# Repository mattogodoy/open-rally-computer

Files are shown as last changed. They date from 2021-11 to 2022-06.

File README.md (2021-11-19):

# Open Rally Computer

An open source tripmaster for navigation rallies

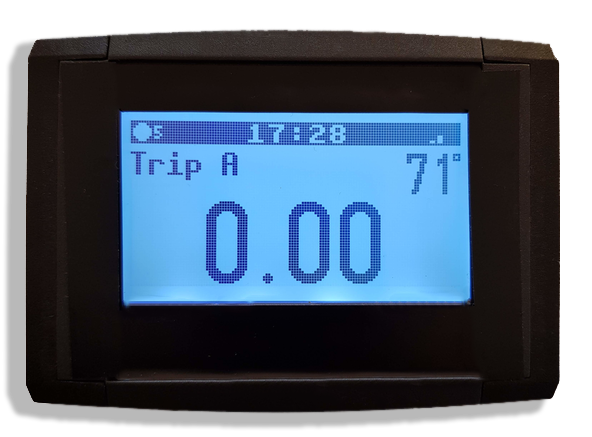
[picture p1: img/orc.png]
Open Rally Computer


## Description

The Open Rally Computer (previously known as [Baja Pro](https://baja.matto.io/)) is a complete tripmaster for navigation rallies.

Some of its features are:

- Based on GPS technology
- Adjustable partial distance odometer
- Total distance odometer
- Speedometer
- Average speed
- Max speed
- Trip time
- Compass (CAP heading)
- Multiple languages and unit systems
- Firmware updates over-the-air

The main goal of this project is to achieve a widely used open-source device that can be improved over time by ourselves, the pilots behind the roadbook.

You can read a detailed writeup of the project here:

- [English version](https://matto.io/open-sourcing-the-baja-pro/)
- [Spanish version](https://matto.io/liberando-el-codigo-del-baja-pro/)

## Schematics and PCB

You can find all the necessary information for fabricating your own copy of the Open Rally Computer PCB in the [pcb](docs/pcb) and [schematics](docs/schematics) folders of this repository.

> **HELP NEEDED**: My knowledge in electronics is self-taught, so I'm sure there are quite a few improvements to be done in this department. If you know electronics and spot something that can be improved, please let me know by opening an issue.

- Previous models of this device have been fabricated at [JLCPCB](https://jlcpcb.com/) with great results and very good prices.
- The system I used to create the PCB was [EasyEDA](https://easyeda.com/). You can find files for the schematics and the PCB in their relative folders. There are also versions for Altium Designer.

> **HELP NEEDED**: I'd like to port these schematics and PCB to KiCad, so we continue with the open source spirit :)
>
> If you know your way around KiCad, I'd really appreciate some help porting this board.

The bill of materials is located in a CSV file in the [bom](docs/pcb/bom) folder. If you find a missing component, please report it by opening an issue.

## User manual

You can find a PDF version of the User Manual in the [manual](docs/manual) folder.

> **HELP NEEDED**: The user manual is currently only in Spanish and it still has a lot of Baja Pro branding that has to be changed to "Open Rally Computer". I'd really appreciate some help transcribing it to Markdown and translating it into other languages, being english the top priority right now.

## Getting Started

These instructions will allow you to compile the project in you local computer. In order to run it you will need an actual device.

### Prerequisites

This project has been developed using VSCode with the PlatformIO plugin, which is is the recommended setup.

- Install [VSCode](https://code.visualstudio.com/)
- Install the [PlatformIO plugin](https://platformio.org/install/ide?install=vscode)
- Clone this repository

```bash
git clone https://github.com/mattogodoy/open-rally-computer.git
```

### Building

To build this project you can open the directory of the repository you just downloaded in VSCode.

Once open, go to the sidebar at the left, PlatformIO -> esp32dev -> General -> Build

The required libraries are already bundled in the `lib` directory of this repo. PlatformIO will automatically try to use them.
If for some reason you are getting compilation errors because of missing libraries, you can always install them manually going to PlatformIO -> PIO Home -> Libraries.

You can find the list of necessary libraries in the file [platformio.ini](platformio.ini).

## Flashing into device

Once the project compiles correctly in your computer, you are ready to flash it into the rally computer.

1. Connect your ESP32 (DevKit or programmer) to your computer via USB.
2. Go to PlatformIO -> esp32dev -> General -> Upload
3. PlatformIO should automatically detect the serial port where your ESP32 is connected, buld the project and flash it for you.

## Contributing

Please read [CONTRIBUTING.md](CONTRIBUTING.md) for details on the process for submitting pull requests.

Also read [CODE_OF_CONDUCT.md](CODE_OF_CONDUCT.md) for details on the code of conduct for this project.

## Versioning

We use [SemVer](http://semver.org/) for versioning.

For a list of available versions, see the [tags on this repository](https://github.com/mattogodoy/open-rally-computer/tags).

## Authors

- **Matías Godoy** - [matto.io](https://matto.io/)

See also the list of [contributors](https://github.com/mattogodoy/open-rally-computer/graphs/contributors) who participated in this project.

## TO-DO

There are a few things I'd like to do in order to improve this project and its repository:

- [x] Build, upload and tag Version 1.0.0 binary as a release
- [x] Translate user manual to english
- [ ] Port the PCB files to KiCad
- [ ] Create proper documentation in GitHub Wiki
- [ ] Create Continuous Integration using GitHub Actions

## License

This project is licensed under the GPL v3 License - see the [LICENSE](LICENSE) file for details.

This is what this means:

1. Anyone can copy, modify and distribute this software.
2. If you do, you have to include the license and copyright notice with each and every distribution.
3. You can use this software privately.
4. You can use this software for commercial purposes.
5. If you build your business based on this code, you have to open-source your whole code base.
6. Any modifications of this code base MUST be distributed with the same license (GPL v3).
7. Any changes made to this code MUST be indicated on distribution.
8. This software is provided without warranty.
9. The software author or license can not be held liable for any damages inflicted by the software.

## Changelog

- **1.0.0**: Initial version
  - The complete project was open sourced, including source code, bill of materials, PCB desings and user manual.

## Contributors

- [turtle3333](https://github.com/turtle3333): User manual translation

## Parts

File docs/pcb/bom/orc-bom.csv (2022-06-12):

ID | Name | Designator | Footprint | Quantity
1 | ERC12864-655 128x64 LCD Display | LCD1 | ERC12864-655 | 1
2 | 2.2uF | C1,C2 | 1206 | 2
3 | 0.33uF | C3 | 1206 | 1
4 | 0.1uF | C4 | 1206 | 1
5 | 10M | R1 | 1206 | 1
6 | 1k | R2 | 1206 | 1
7 | 10uF | C5 | 1206 | 1
8 | Thermistor | U4 | THERMISTOR-PCB | 1
9 | 1N4007 | D1 | SOD-123F | 1
10 | DC-DC stepdown | U2 | DC-DC STEPDOWN | 1
11 | uBlox Neo 6M, 8M or BN-180 GPS modules (all compatible) | GPS1 | GY-NEO6MV2 | 1
12 | ESP32_WROOM32 | X1 | WROOM32 | 1
13 | AMS1117-3.3 | U3 | SOT-223 | 1
14 | 2.4k | R3,R4 | 1206 | 2
15 | Header-Female-2.54_1x6 | P4 | HDR-6X1/2.54 | 1
16 | 10k | R5,R6 | 1206 | 2
17 | Header-Female-2.54_1x4 | P1 | HDR-4X1/2.54 | 1
18 | Header-Female-2.54_1x2 | P2 | HDR-1X2/2.54 | 1
19 | 22uF | C6 | 1206 | 1
20 | FM24CL04B-GTR_C365762 | U1 | SOIC-8_150MIL | 1

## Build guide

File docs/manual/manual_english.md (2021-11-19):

# Open Rally Computer

## User manual

- Introduction
- Installation
   - Power
   - Command
- Turning on/off
- Screens
- Navigation between screens
   - Status bar
   - Odometer
   - Speed
   - Travel time
   - Course
- Setting
   - Access the configuration menu
   - Navigate within settings
   - Reset trip
   - Language
   - Accuracy
   - Units
   - Time zone
   - Backlight
   - Quickview
   - Invert Screen
   - GPS data
   - Update firmware
   - Version
   - Factory values

## Introduction

This is the user manual for the **Open Rally Computer**. Here you will find everything you need to install and get the most out of your new tripmaster.
If you have any suggestion for improvement to this manual, do not hesitate to reach us at <https://github.com/mattogodoy/open-rally-computer/>

## Installation

The **Open Rally Computer** allows a simple installation thanks to the fact that it works only with GPS, so it is not necessary to install magnetic wheel sensors.
The clamping screws are **5mm** and have a **37mm** gap between them, which allows it to be installed without problems on supports intended for other
devices like the _ICO_.

### Power

The **Open Rally Computer** runs on **12 volts**, so it can be connected directly to the battery of the motorcycle.
The use of a 1A fuse is recommended but not essential, since this device it has a very low electricity consumption.
**IMPORTANT**
The power cable has 3 smaller cables inside:

1. **Black**: POSITIVE (+)
2. **Blue**: NEGATIVE (-)
3. **Brown**: _not used, do not connect_

Contrary to common convention, **the black wire on the Open Rally Computer is positive**. This is one design decision that, although not standard, allows it to be powered with electricity distribution modules such as the _F2R Rallye Power Box_ or with power cables from other brands like the _ICO_.
Although the **Open Rally Computer** has a reverse polarity protection mechanism, it is advisable to pay special attention to the colors of the cables and connect them correctly.

### Command

To install the remote in your handlebar you must:

1. Remove the Allen screws that keep it closed.
2. Carefully open the two pieces that make up the body of the control (CAUTION, both pieces will be joined by a pair of cables).
3. Choose the direction of the cable exit: the control body has two notches; one on the right and one on the left. This allows the remote to be installed in any of the both sides of the handlebar.
4. Place the control on the handlebar of the motorcycle **taking special care that the cable does not remain pressed between the handlebar and the controller**.
5. Tighten the screws without exerting excessive pressure. The body of the controls is made of aluminum and excessive screw pressure could ruin the threads.
The remote has 3 buttons with different functions based on the screen on which you find:
- **Upper front**: Increase / Go up
- **Lower front**: Reduce / Go down
- **Rear**: Change screen / Partial reset / Access menu / Select

## Turning on/off

The **Open Rally Computer** does not have an on / off switch, so the management of the power is left to the pilot.
For reasons inherent to the operation of the GPS system, if the **Open Rally Computer** has not been used for a long period of time, or if it is turned on in a location far from where it was last used, it may take a few minutes for the device to get a signal from GPS satellites.
It is for this reason that it is advisable to always turn on the **Open Rally Computer** a few minutes before starting the tour.
That said, the **Open Rally Computer** is capable of obtaining positioning information from both the constellation of **GPS** satellites as well as **Glonass** and **Galileo**, which allows the satellite reception wait time is quite low and the accuracy is higher than that of other devices.

## Screens

There are several screens that show useful information when navigating using a roadbook. The distribution of information within the screens and the way in which that the data are grouped is designed to facilitate the pilot reading the data simply sight and with minimal effort.

## Navigating between screens

To change the screen, simply press the selection button on the remote (rear button)

### Status bar

At the top of all screens (except for the configuration screens) there is a bar of State.

In this bar you can see some useful information:
- In the left corner you can see a disc. If the disc is spinning it means that the GPS module is searching for satellites to obtain your location. Once you have a reliable location, the disk icon will change to bars indicating the quality of the signal.
- In the center is the current time. The time values for the clock are obtained from the GPS module, so it has great precision. This implies that until there is no GPS signal, the time will not be correct. **IMPORTANT:** Remember to set the time zone of the place where you are (_see time zone configuration section_).
- In the right corner you can see the number of satellites of which the GPS module receives signal. The minimum required to obtain a valid location is **4 satellites**, although in this case more is better.

### Odometer

The screen you will most likely see most of the time is the odometer.
In it you can see:
- **Total distance** in the upper left: Counts the distance traveled from the last total distance reset (from the configuration menu). This distance **does NOT** vary when manually adjusting the partial distance using the buttons. It can be considered as the total and real distance that you have traveled during a complete stage.
- **Partial distance** in the center: Counts the distance traveled since the last reset of partial distance.
- **Heading** in the upper right: The heading is indicated in degrees, with 0º being North and 180º the South.

**Controls**
On this screen, the remote control buttons fulfill the following functions:
- **Up**: Increases partial distance. If the precision of the distance is set to 1 decimal, adds 100 meters. If it is set to 2 decimal places, it adds 10 meters. Keeping the button pressed will quickly increase to do changes of great distances.
- **Down**: Decreases partial distance. If the distance accuracy is set to 1 decimal, it will subtract 100 meters. If it is set to 2 decimal places, it subtracts 10 meters. Keeping the button pressed will quickly decrease to make changes of great distances.
- **Selection**: If pressed briefly, it switches to the next screen. Keeping it pressed resets the partial distance to 0. This **DOES NOT** affect the total distance.

### Speed

On this screen you can see:
- The speed at which you are currently traveling.
- The average speed since the last total distance reset carried out from the configuration menu.
**NOTE**: This average includes the time the motorcycle is not moving. This is especially useful to know your real average for regularity rallies.
- The maximum speed reached since the last total distance reset carried out from the settings menu. This value is useful to avoid being penalized in rallies where the maximum speed is limited.
**Controls**
On this screen, the remote control buttons fulfill the following functions:
- **Up**: If the QuickView functionality is enabled, displays the Odometer screen while holding down the button.
- **Down**: If the QuickView functionality is enabled, displays the Odometer screen while holding down the button.
- **Selection**: Short press switches to next screen. Long press accesses the configuration screen.
### Travel time

In this screen you can see the time elapsed since the last total distance reset performed from the settings menu, including the time the motorcycle has been stopped. This is especially useful for regularity rallies.
**Controls**
In this screen, the remote control buttons fulfill the following functions:
- **Up**: If the QuickView functionality is enabled, displays the Odometer screen while holding down the button.
- **Down**: If QuickView functionality is enabled, displays the Odometer screen while holding down the button.
- **Selection**: If pressed briefly, it switches to the next screen. Long press accesses the configuration screen.

### Course

Indicates the current heading in degrees, being 0º North and 180º South.
**NOTE**: Heading is calculated by drawing vectors between GPS location points, so this value is not valid if the motorcycle is not moving.
**Controls**
In this screen, the remote control buttons fulfill the following functions:
- **Up**: If the QuickView functionality is enabled, displays the Odometer screen while holding down the button.
- **Down**: If QuickView functionality is enabled, displays the Odometer screen while holding down the button.
- **Selection**: If pressed briefly, it switches to the next screen. Long press accesses the configuration screen.

## Settings

This is the screen from where the **Open Rally Computer** is configured.

### Access the configuration menu

To access the configuration menu, **while at any screen other than the Odometer**, press and hold the **Select** button (rear button of controller) for a few seconds.

### Navigate within settings

To select options within the setup menu using the remote:
- **Up**: Upper front button
- **Lower**: Lower front button
- **Select**: Back button
- **Cancel**: Press and hold the back button
- **Exit menu**: Press and hold the back button

### Reset trip

Use this option before starting each stage of a rally. This resets:
- Total distance
- Partial distance
- Average speed
- Maximum speed
- Travel time

### Language

The **Open Rally Computer** can be configured in the following languages:
- Spanish
- English
Select the one that best suits your needs.

### Accuracy

The accuracy level can be set between:
- **One decimal**: Distances show increments every 100 meters. When manually adjusting, it will add or subtract 100 meters to the partial distance.
- **Two decimal places**: Distances show increments every 10 meters. When manually adjusting, it will add or subtract 10 meters to the partial distance.

### Units

The units system can be configured as:
- Metric (km / h, mm)
- Imperial (mph, in)
This option affects distance measurements. In the **Metric** system **kilometers** are used and in the
**Imperial** system **miles** are used.
**NOTE**: Changing this option resets all time, speed and distance values.

### Time zone

Allows you to select the time zone you are in to obtain a correct value for the current time.
The range of **UTC** values is between **- 12** and **+ 14.**

### Backlight

Select how bright the screen is.
The range of values is from **0** (light off) to **10** (maximum intensity). This is especially useful for low-light or night stages where the brightness of the display may affect the visibility of the pilot.

### Quickview

This functionality allows you to quickly and temporarily see the **Odometer** screen when you are on any other screen.
If this option is activated, whenever you are on a screen other than **Odometer**, holding down the upper or lower button on the remote will temporarily switch to the **Odometer** display. Releasing the button on the controller will return to the screen you were previously.
This is especially useful for sections where you need to pay special attention to the **Heading** or **Speed **, but from time to time you need to quickly see the distance traveled.

### Invert Screen

Allows you to invert the screen image 180º.
This is useful in case you have to install the **Open Rally Computer** in an inverted position.

### GPS data

Raw data from the GPS module among which you can find Latitude, Longitude, Height and more.
This could be useful in the event that you need to share your current location with somebody.

### Update firmware

Update the **Open Rally Computer** firmware to the latest version.
The description of this functionality will be updated in this manual as soon as a firmware update is released.

### Version

It shows the serial number of your device and its current firmware version.

### Factory settings

Restores the **Open Rally Computer** values and settings to their factory state.

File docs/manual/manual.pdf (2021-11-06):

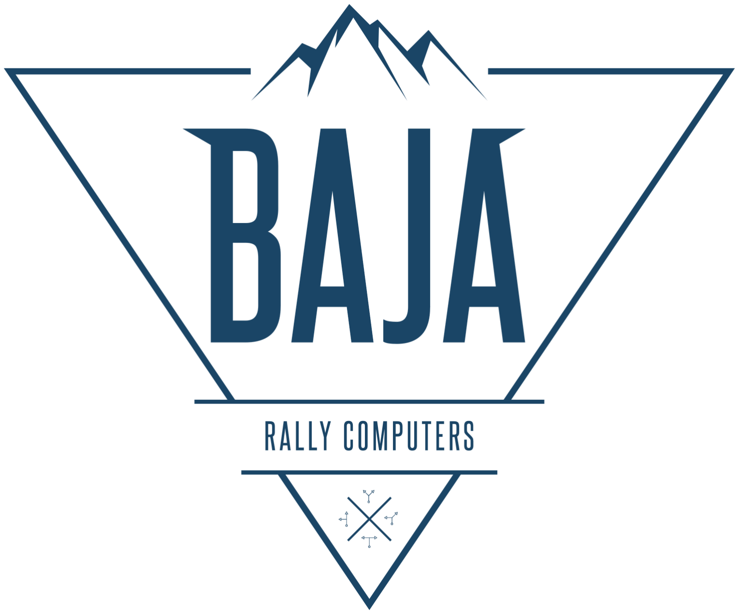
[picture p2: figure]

# BAJA PRO

# Manual de usuario

Introducción | 3
Contenido de la caja | 3
Instalación | 3
Alimentación | 3
Mando | 4
Encendido | 5
Pantallas | 5
Navegación entre pantallas | 5
Barra de estado | 5
Odómetro | 6
Velocidad | 7
Tiempo de trayecto | 8
Rumbo | 9
Configuración | 10
Acceder al menú de configuración | 10
Navegar dentro de la configuración | 10
Resetear viaje | 10
Idioma | 11
Precisión | 11
Unidades | 11
Zona Horaria | 11
Luz de pantalla | 12
Quickview | 12
Invertir Pantalla | 12
Datos de GPS | 12
Actualizar firmware | 13
Versión | 13
Valores de fábrica | 13

# Introducción

Éste es el manual de uso para el Baja Pro v4. Aquí encontrarás todo lo necesario para instalar y sacar el máximo provecho a tu nuevo Baja.

Ante cualquier sugerencia de mejora para éste manual, no dudes en escribir a baja@matto.io

# Contenido de la caja

En la caja de este producto encontrarás:

- El Baja Pro
- Mando para manillar con 3 botones
- Cable de alimentación

# Instalación

El Baja Pro permite una instalación simple gracias a que funciona sólo con GPS, por lo que no es necesario instalar sensores magnéticos de rueda.

Los tornillos de sujeción del Baja Pro son de 5 mm y tienen una separación de 37 mm entre ellos, lo cual le permite ser instalado sin problemas en soportes pensados para otros dispositivos como el ICO.

## Alimentación

El Baja Pro funciona con 12 volts, por lo que se puede conectar directamente a la batería de la moto.
El uso de un fusible de 1A es recomendable pero no indispensable, dado que este dispositivo tiene un consumo eléctrico muy bajo.

IMPORTANTE
El cable de alimentación del Baja Pro lleva 3 cables dentro:
1. Negro: POSITIVO (+)
2. Azul: NEGATIVO (-)
3. Marrón: no se usa, no conectar

Contrario a la convención común, el cable negro en el Baja Pro es positivo. Esto es una decisión de diseño que, aunque no es estándar, permite alimentar el Baja Pro con módulos de distribución de electricidad como el F2R Rallye Power Box o con cables de electricidad de otras marcas como el de los ICO.

Si bien el Baja Pro dispone de un mecanismo de protección contra inversión de polaridad, es recomendable prestar especial atención a los colores de los cables y conectarlos correctamente.

## Mando

Para instalar el mando incluído con el Baja Pro, debes:

1. Quitar los tornillos allen que lo mantienen cerrado.
2. Abrir con cuidado las dos piezas que conforman el cuerpo del mando (CUIDADO, ambas piezas quedarán unidas por un par de cables).
3. Elegir la dirección de la salida del cable: el cuerpo del mando tiene dos muescas; una a la derecha y otra a la izquierda. Esto permite la instalación del mando en cualquiera de los dos lados del manillar.
4. Colocar el mando sobre el manillar de la moto con especial cuidado de que no quede ningún cable presionado entre el manillar y el mando.
5. Ajustar los tornillos sin ejercer excesiva presión. El cuerpo de los mandos es de aluminio y el exceso de presión de los tornillos podría arruinar las roscas.

El mando dispone de 3 botones con diferentes funciones en base a la pantalla en que te encuentres:

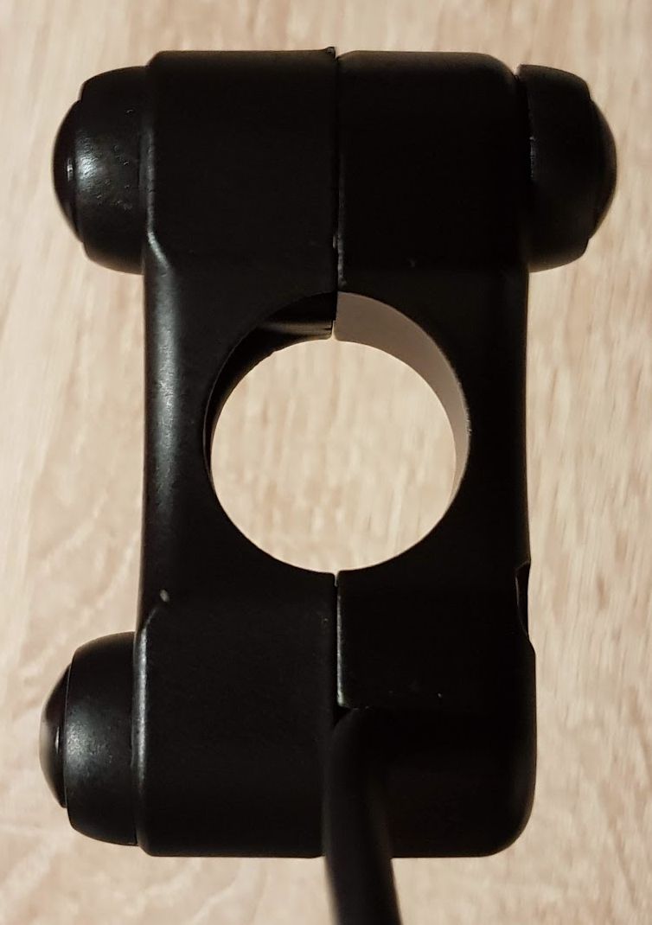
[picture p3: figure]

- Frontal superior: Aumentar / Subir
- Frontal inferior: Reducir / Bajar
- Posterior: Cambiar pantalla / Resetear parcial / Acceder a menú / Seleccionar

# Encendido

El Baja Pro no dispone de un switch de encendido/apagado, por lo que la administración de la energía queda a cargo del piloto.

Por razones inherentes al funcionamiento del sistema GPS, si el Baja Pro no ha sido utilizado durante un largo periodo de tiempo, o si es encendido en una ubicación lejana a la que fue utilizado por última vez, es posible que el dispositivo demore unos minutos en obtener señal de los satélites GPS.
Es por éste motivo que es recomendable siempre encender el Baja Pro algunos minutos antes de comenzar el recorrido.

Dicho esto, el Baja Pro es capaz de obtener información de posicionamiento tanto de la constelación de satélites GPS como también de Glonass y Galileo, lo cual permite que el tiempo de espera de recepción de satélites sea bastante bajo y la precisión sea superior a la de otros dispositivos.

# Pantallas

El Baja Pro dispone de varias pantallas que muestra información útil a la hora de navegar utilizando un roadbook. La distribución de información dentro de las pantallas y la manera en la que los datos están agrupados está pensada para facilitar al piloto la lectura de datos a simple vista y con un esfuerzo mínimo.

# Navegación entre pantallas

Para cambiar de pantalla simplemente presiona el botón de selección del mando (botón trasero) durante un

## Barra de estado

En la parte superior de todas las pantallas (a excepción de las de configuración) hay una barra de estado.

En esta barra puedes ver información importante:

- En la esquina izquierda se puede ver un disco. Si el disco está girando significa que el módulo GPS está buscando satélites para obtener su ubicación. Una vez obtenida una ubicación fiable, el icono del disco cambiará a unas barras que indicarán la calidad de la señal.
- En el centro se encuentra la hora actual. Los valores de la hora se obtienen del módulo GPS, por lo que tiene gran precisión. Esto implica que hasta no tener señal GPS la hora no es correcta. IMPORTANTE: Recuerda configurar la zona horaria del lugar en que te encuentras (ver apartado de configuración de zona horaria).
- En la esquina derecha se puede ver el número de satélites de los cuales el módulo GPS recibe señal. El mínimo necesario para obtener una ubicación válida es de 4 satélites, aunque en este caso más es mejor.

## Odómetro

La pantalla que seguramente verás durante la mayor parte del tiempo es la del odómetro.

En ella puedes ver:

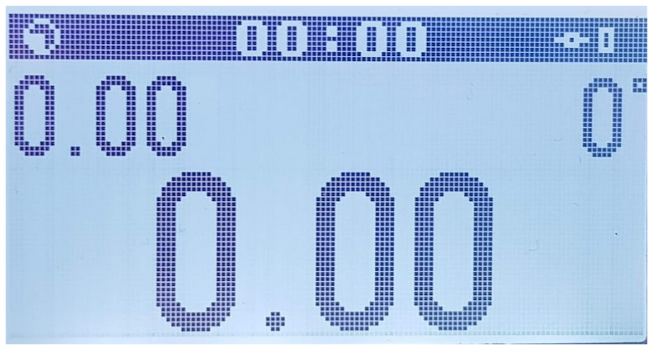
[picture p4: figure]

- Distancia total en la parte superior izquierda: Cuenta la distancia recorrida desde el último reset de distancia total (desde el menú de configuración). Esta distancia NO varía al recalar. Se puede considerar como la distancia total y real que has recorrido durante una etapa completa.
- Distancia parcial en el centro: Cuenta la distancia recorrida desde el último reset de distancia parcial.
- Rumbo en la parte superior derecha: Se indica el rumbo en grados, siendo 0º el Norte y 180º el Sur.

Controles

En esta pantalla los botones del mando cumplen las siguientes funciones:

- Arriba: Recala distancia parcial hacia arriba (aumenta). Si la precisión de la distancia está configurada en 1 decimal, suma 100 metros. Si está configurada en 2 decimales, suma 10 metros. Manteniendo el botón presionado aumentará rápidamente para hacer cambios de grandes distancias.
- Abajo: Recala distancia parcial hacia abajo (reduce). Si la precisión de la distancia está configurada en 1 decimal, resta 100 metros. Si está configurada en 2 decimales, resta 10 metros. Manteniendo el botón presionado reducirá rápidamente para hacer cambios de grandes distancias.
- Selección: Si se presiona brevemente, cambia a la siguiente pantalla. Si se mantiene presionado resetea la distancia parcial a 0. Esto NO afecta a la distancia total.

## Velocidad

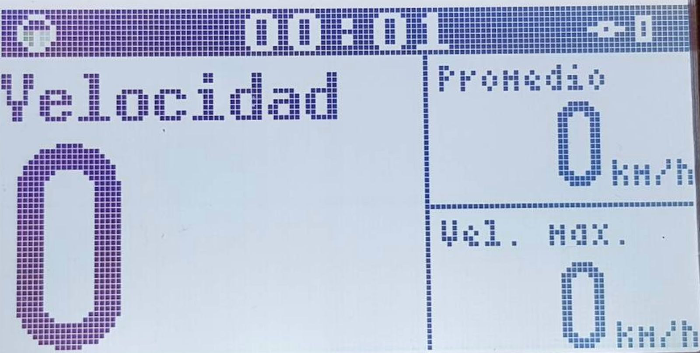
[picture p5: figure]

En esta pantalla puedes ver:

- La velocidad a la que te mueves actualmente.
- La velocidad promedio desde el último reset efectuado desde el menú de configuración. NOTA: Este promedio incluye el tiempo en que la moto no está en movimiento. Esto es especialmente útil para saber tu promedio real el rallies de regularidad.
- La velocidad máxima alcanzada desde el último reset efectuado desde el menú de configuración. Este valor es útil para evitar ser penalizado en rallies donde la velocidad máxima está limitada.

Controles

En esta pantalla los botones del mando cumplen las siguientes funciones:

- Arriba: Si la funcionalidad de QuickView está activada, muestra la pantalla de Odómetro mientras se mantiene el botón presionado.

- Abajo: Si la funcionalidad de QuickView está activada, muestra la pantalla de Odómetro mientras se mantiene el botón presionado.
- Selección: Si se presiona brevemente, cambia a la siguiente pantalla. Si se mantiene presionado accede a la pantalla de configuración.

## Tiempo de trayecto

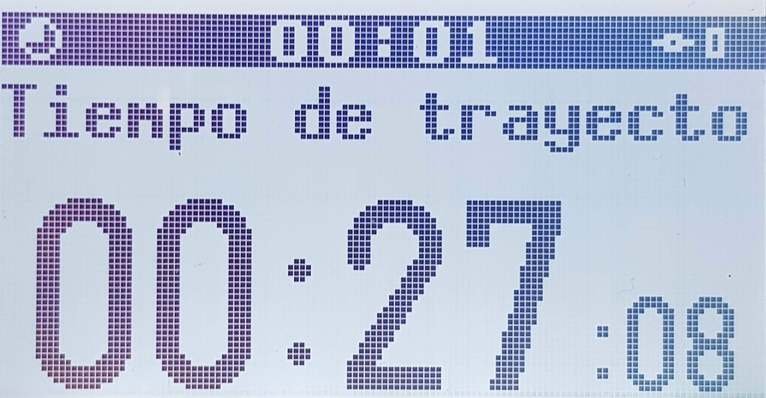
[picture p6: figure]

En esta pantalla se puede ver el tiempo transcurrido desde el último reseteo efectuado desde el menú de configuración, incluido el tiempo en que la moto ha estado detenida. Esto es especialmente útil para rallies de regularidad.

Controles

En esta pantalla los botones del mando cumplen las siguientes funciones:

- Arriba: Si la funcionalidad de QuickView está activada, muestra la pantalla de Odómetro mientras se mantiene el botón presionado.
- Abajo: Si la funcionalidad de QuickView está activada, muestra la pantalla de Odómetro mientras se mantiene el botón presionado.
- Selección: Si se presiona brevemente, cambia a la siguiente pantalla. Si se mantiene presionado accede a la pantalla de configuración.

## Rumbo

Indica el rumbo actual en grados, siendo 0º el Norte y 180º el Sur.

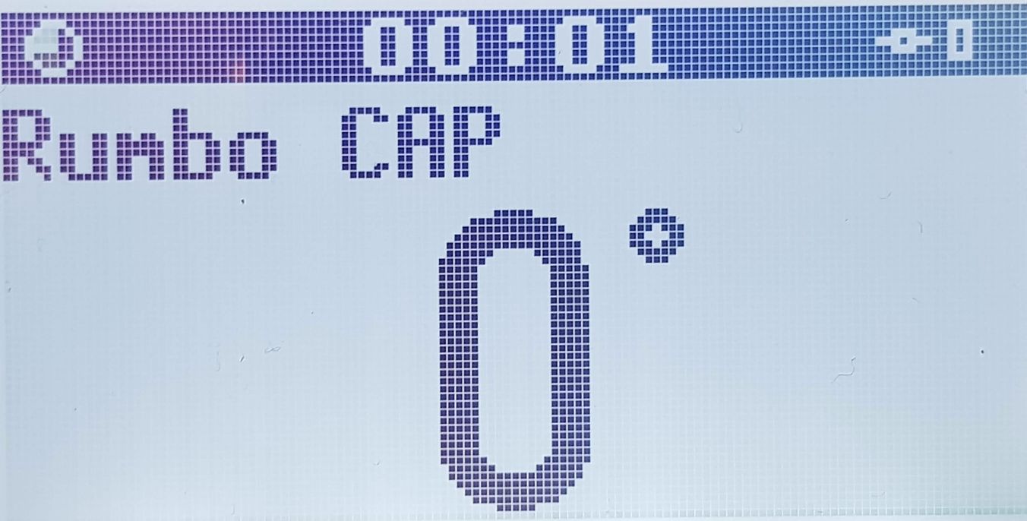
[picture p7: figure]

NOTA: El rumbo es calculado trazando vectores entre puntos de ubicación de GPS, por lo que este valor no es válido si la moto no se encuentra en movimiento.

Controles

En esta pantalla los botones del mando cumplen las siguientes funciones:

- Arriba: Si la funcionalidad de QuickView está activada, muestra la pantalla de Odómetro mientras se mantiene el botón presionado.
- Abajo: Si la funcionalidad de QuickView está activada, muestra la pantalla de Odómetro mientras se mantiene el botón presionado.
- Selección: Si se presiona brevemente, cambia a la siguiente pantalla. Si se mantiene presionado accede a la pantalla de configuración.

# Configuración

Esta es la pantalla desde la que se configura el Baja Pro.

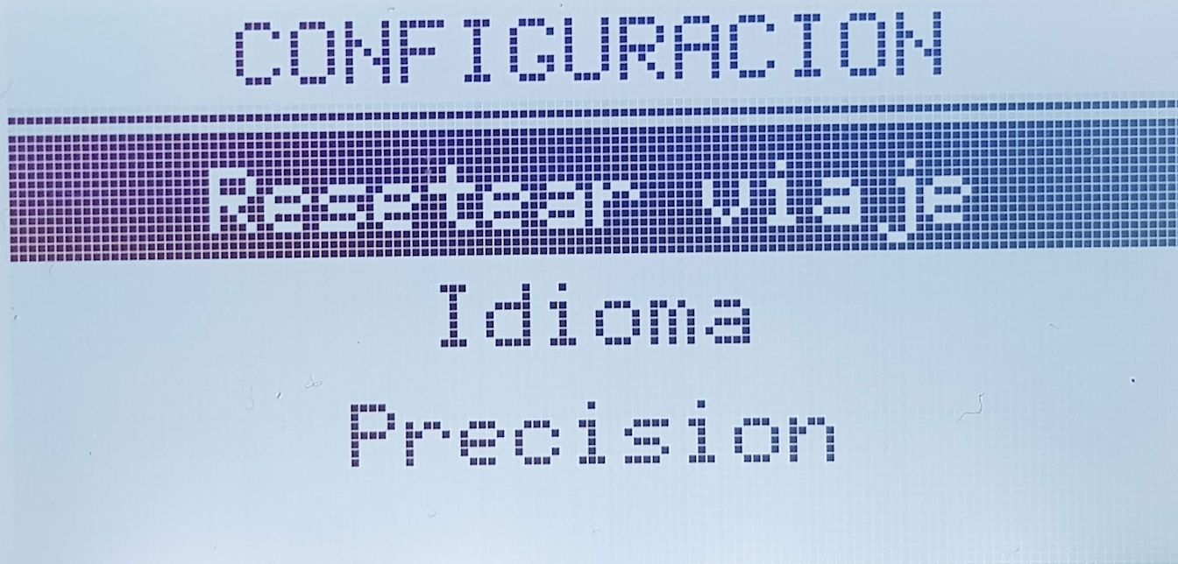
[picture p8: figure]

## Acceder al menú de configuración

Para acceder al menú de configuración, estando en cualquier pantalla que NO sea la de Odómetro, mantén presionado el botón de Selección (botón posterior del mando) durante algunos segundos.

## Navegar dentro de la configuración

Para seleccionar opciones dentro del menú de configuración usando el mando:

- Subir: Botón frontal superior
- Bajar: Botón frontal inferior
- Seleccionar: Botón posterior
- Cancelar: Mantener presionado el botón posterior
- Salir del menú: Mantener presionado el botón posterior

## Resetear viaje

Utiliza esta opción antes de empezar cada etapa de un rally. Esto resetea:

- Distancia total
- Distancia parcial
- Velocidad promedio
- Velocidad máxima
- Tiempo de trayecto

## Idioma

El Baja Pro se puede configurar en los siguientes idiomas:

- Español
- Inglés

Selecciona el que mejor se ajuste a tus necesidades.

## Precisión

El nivel de precisión del Baja Pro se puede configurar entre:

- Un decimal: Las distancias muestran incrementos cada 100 metros. Al recalar se sumará o restará 100 metros a la distancia parcial.
- Dos decimales: Las distancias muestran incrementos cada 10 metros. Al recalar se sumará o restará 10 metros a la distancia parcial.

## Unidades

El sistema de unidades del Baja Pro puede ser configurado en:

- Métrico (km/h, mm)
- Imperial (mph / in)

Esta opción afecta a medidas de distancia. En el sistema Métrico se utilizan kilómetros y en el sistema Imperial se utilizan millas.

NOTA: Al cambiar esta opción se resetean todos los valores de tiempo, velocidad y distancia.

## Zona Horaria

Permite seleccionar la zona horaria en la que te encuentras para obtener un valor correcto de la hora actual.

El rango de valores UTC está entre -12 y +14.

## Luz de pantalla

Selecciona la intensidad del brillo de la pantalla.

El rango de valores va desde 0 (luz apagada) a 10 (máxima intensidad).

Esto es especialmente útil para etapas nocturnas o con poca luz en las que el brillo de la pantalla puede afectar a la visibilidad del piloto.

## Quickview

Esta funcionalidad permite volver rápidamente y de manera temporal a la pantalla de
Odómetro cuando te encuentras en cualquier otra pantalla.

Si esta opción está activada, siempre que estés en una pantalla que no sea la de Odómetro, al mantener presionado el botón superior o inferior del mando podrás ver temporalmente la pantalla de Odómetro. Al soltar el botón del mando volverás a la pantalla en la que te encontrabas anteriormente.

Esto es especialmente útil para tramos en los que necesitas prestar especial atención al Rumbo o a la Velocidad, pero de tanto en tanto necesitas ver rápidamente la distancia recorrida.

## Invertir Pantalla

Permite invertir la imagen de la pantalla en 180º.

Esto es útil para el caso en que tengas que instalar el Baja Pro en posición invertida.

## Datos de GPS

Datos en bruto del módulo de GPS entre los que puedes encontrar Latitud, Longitud, Altura y más.

Esto podría ser de utilidad en el caso de que tengas que compartir tu ubicación actual con alguien.

## Actualizar firmware

Actualiza el firmware del Baja Pro a la última versión.

La descripción de esta funcionalidad será actualizada en este manual en cuanto se libere una actualización del firmware.

## Versión

Muestra el número de serie de tu Baja Pro y la versión actual del firmware instalada en el dispositivo.

## Valores de fábrica

Restaura todos los valores y configuraciones del Baja Pro a su estado de fábrica.

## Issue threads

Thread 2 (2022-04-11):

Help with Open Rally Computer, please!

HeadOfTheSPEDs, 2022-04-11:
@mattogodoy

Hi Matias,
I'm hoping you've seen my email, tweet, and/or post on ADVRider. Even more so, hoping you might be willing to help me out just a bit on building your Open Rally Computer.

Thank you so much in advance/fingers crossed that you see this!

Relevant ADVRider post is at [https://www.advrider.com/f/threads/building-an-ico-checkmate-or-rallyemax-clone.1546305/#post-44420029](https://github.com/HeadOfTheSPEDs/reachingOut/issues/url).

mattogodoy, 2022-04-11:
Email replied. Closing issue.

Closed 2022-04-11.

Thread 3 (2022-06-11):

GPS Module in BOM

adrianhoffmann11, 2022-06-11:
I see that you have included the `uBlox Neo 6M breakout board module` in the [BOM](https://github.com/mattogodoy/open-rally-computer/blob/master/docs/pcb/bom/orc-bom.csv). However, based on your [blog post](https://matto.io/open-sourcing-the-baja-pro/#version-4) and PCB design, it appears that we should instead be using the `BN-180 GPS Module UART TTL` module. Which module is compatible with the PCB and code? Thanks!

mattogodoy, 2022-06-12:
Hi!
Well spotted, sorry about that. The uBlox Neo 6M, 8M and the BN-180 GPS modules are all compatible, so you can use any of them with no changes in the firmware. My recommendation is the BN-180; gets satellites faster and has galileo compatibility.
I'll modify this in the BOM.

Closed 2022-06-12.

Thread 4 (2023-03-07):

httpclient compile issue

iulianb0n, 2023-03-07:
Hi,

I just built the hardware for the open rally computer, wanted to program it, followed instructions and ended up with the issue that is further on. What could be the problem do you think?
Thank you!

Processing esp32dev (platform: espressif32; board: esp32dev; framework: arduino)
----------------------------------------------------------------------------------------------------------------------------------------------------------------------------------------------------------------Verbose mode can be enabled via `-v, --verbose` option
CONFIGURATION: https://docs.platformio.org/page/boards/espressif32/esp32dev.html
PLATFORM: Espressif 32 (6.0.1) > Espressif ESP32 Dev Module
HARDWARE: ESP32 240MHz, 320KB RAM, 4MB Flash
DEBUG: Current (cmsis-dap) External (cmsis-dap, esp-bridge, esp-prog, iot-bus-jtag, jlink, minimodule, olimex-arm-usb-ocd, olimex-arm-usb-ocd-h, olimex-arm-usb-tiny-h, olimex-jtag-tiny, tumpa)
PACKAGES:
 - framework-arduinoespressif32 @ 3.20006.221224 (2.0.6)
 - tool-esptoolpy @ 1.40400.0 (4.4.0)
 - toolchain-xtensa-esp32 @ 8.4.0+2021r2-patch5
LDF: Library Dependency Finder -> https://bit.ly/configure-pio-ldf
LDF Modes: Finder ~ chain, Compatibility ~ soft
Found 41 compatible libraries
Scanning dependencies...
Dependency Graph
|-- U8g2 @ 2.26.1
|   |-- SPI @ 2.0.0
|   |-- Wire @ 2.0.0
|-- r89m Buttons @ 2.0.1
|-- r89m PushButton @ 1.0.0
|   |-- r89m Buttons @ 2.0.1
|   |-- Bounce2 @ 2.52
|-- TinyGPSPlus @ 1.0.2
|-- Time @ 1.5
|-- FRAM_MB85RC_I2C @ 0.0.0+20230307194407
|   |-- Wire @ 2.0.0
|-- Bounce2 @ 2.52
|-- Wire @ 2.0.0
|-- HTTPClient @ 2.0.0
|   |-- WiFi @ 2.0.0
|   |-- WiFiClientSecure @ 2.0.0
|   |   |-- WiFi @ 2.0.0
|   |-- Time @ 1.5
|-- Update @ 2.0.0
|-- WiFi @ 2.0.0
Building in debug mode
Compiling .pio\build\esp32dev\src\buttons.cpp.o
.
.
Compiling .pio\build\esp32dev\FrameworkArduino\FirmwareMSC.cpp.o
C:/Users/banic/.platformio/packages/framework-arduinoespressif32/libraries/HTTPClient/src/HTTPClient.cpp: In member function 'void HTTPClient::setCookie(String, String)':
C:/Users/banic/.platformio/packages/framework-arduinoespressif32/libraries/HTTPClient/src/HTTPClient.cpp:1554:15: error: aggregate 'tm tm' has incomplete type and cannot be defined
     struct tm tm;
               ^~
C:/Users/banic/.platformio/packages/framework-arduinoespressif32/libraries/HTTPClient/src/HTTPClient.cpp:1555:5: error: 'strptime' was not declared in this scope
     strptime(date.c_str(), HTTP_TIME_PATTERN, &tm);
     ^~~~~~~~
C:/Users/banic/.platformio/packages/framework-arduinoespressif32/libraries/HTTPClient/src/HTTPClient.cpp:1555:5: note: suggested alternative: 'st_ctime'
     strptime(date.c_str(), HTTP_TIME_PATTERN, &tm);
     ^~~~~~~~
     st_ctime
C:/Users/banic/.platformio/packages/framework-arduinoespressif32/libraries/HTTPClient/src/HTTPClient.cpp:1556:19: error: 'mktime' was not declared in this scope
     cookie.date = mktime(&tm);
                   ^~~~~~
C:/Users/banic/.platformio/packages/framework-arduinoespressif32/libraries/HTTPClient/src/HTTPClient.cpp:1556:19: note: suggested alternative: 'mktemp'
     cookie.date = mktime(&tm);
                   ^~~~~~
                   mktemp
C:/Users/banic/.platformio/packages/framework-arduinoespressif32/libraries/HTTPClient/src/HTTPClient.cpp:1643:24: error: 'time' was not declared in this scope
     time_t now_local = time(NULL);
                        ^~~~
C:/Users/banic/.platformio/packages/framework-arduinoespressif32/libraries/HTTPClient/src/HTTPClient.cpp:1643:24: note: suggested alternative: 'tone'
     time_t now_local = time(NULL);
                        ^~~~
                        tone
C:/Users/banic/.platformio/packages/framework-arduinoespressif32/libraries/HTTPClient/src/HTTPClient.cpp:1644:29: error: 'gmtime' was not declared in this scope
     time_t now_gmt = mktime(gmtime(&now_local));
                             ^~~~~~
C:/Users/banic/.platformio/packages/framework-arduinoespressif32/libraries/HTTPClient/src/HTTPClient.cpp:1644:29: note: suggested alternative: 'getSize'
     time_t now_gmt = mktime(gmtime(&now_local));
                             ^~~~~~
                             getSize
C:/Users/banic/.platformio/packages/framework-arduinoespressif32/libraries/HTTPClient/src/HTTPClient.cpp: In member function 'bool HTTPClient::generateCookieString(String*)':
C:/Users/banic/.platformio/packages/framework-arduinoespressif32/libraries/HTTPClient/src/HTTPClient.cpp:1670:24: error: 'time' was not declared in this scope
     time_t now_local = time(NULL);
                        ^~~~
C:/Users/banic/.platformio/packages/framework-arduinoespressif32/libraries/HTTPClient/src/HTTPClient.cpp:1670:24: note: suggested alternative: 'tone'
     time_t now_local = time(NULL);
                        ^~~~
                        tone
C:/Users/banic/.platformio/packages/framework-arduinoespressif32/libraries/HTTPClient/src/HTTPClient.cpp:1671:29: error: 'gmtime' was not declared in this scope
     time_t now_gmt = mktime(gmtime(&now_local));
                             ^~~~~~
C:/Users/banic/.platformio/packages/framework-arduinoespressif32/libraries/HTTPClient/src/HTTPClient.cpp:1671:29: note: suggested alternative: 'getSize'
     time_t now_gmt = mktime(gmtime(&now_local));
                             ^~~~~~
                             getSize
C:/Users/banic/.platformio/packages/framework-arduinoespressif32/libraries/HTTPClient/src/HTTPClient.cpp:1671:22: error: 'mktime' was not declared in this scope
     time_t now_gmt = mktime(gmtime(&now_local));
                      ^~~~~~
C:/Users/banic/.platformio/packages/framework-arduinoespressif32/libraries/HTTPClient/src/HTTPClient.cpp:1671:22: note: suggested alternative: 'mktemp'
     time_t now_gmt = mktime(gmtime(&now_local));
                      ^~~~~~
                      mktemp
Compiling .pio\build\esp32dev\FrameworkArduino\FunctionalInterrupt.cpp.o
*** [.pio\build\esp32dev\libec6\HTTPClient\HTTPClient.cpp.o] Error 1

mattogodoy, 2023-03-08:
Hello!

It seems like the HTTPClient library is complaining.
My guess is that because this project is now 2 years old, that library must have been updated, and this code is no longer compatible.

Sadly I don't have the time to take a look into it, but it should not be a difficult fix to make.
The HTTPClient library is used to check if a new version of the firmware is online, but since I'm not pushing new versions since 2 years ago it's not useful right now. You could even comment out the parts of the code that use it (in https://github.com/mattogodoy/open-rally-computer/blob/master/src/ota.cpp).

If you decide to fix it instead of commenting out your code, I'd appreciate a Pull Request to merge the fix into this project.
Thanks a good luck!

iulianb0n, 2023-03-08:
Thank you for the response and temporary fix, will have a go at doing a full fix, once I understand what needs to be done(almost complete noob at this).

mattogodoy, 2023-03-08:
No problem! Have fun :)

Closed 2023-03-08.

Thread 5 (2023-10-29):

HTML Falla la OTA no compila

casidus, 2023-10-29:
Falla al compilar el codigo ya que la libreria HTTP no existe ya, lo he solucionado eliminado el codigo que hace referencia a esa funcion, subo los archivos aqui ya que esta en varias partes

https://www.dropbox.com/scl/fi/so07o1nnn2j7e84ovofg6/open-rally-computer.rar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

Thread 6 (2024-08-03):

fork and license?

pcace, 2024-08-03:
Hi there, i have found your wonderful ORC project. since some time i have played around using my own fork. changed bits here and there. now i am wondering - can i do that in terms of license ( it is just a private  playground for me, with no intention to make any money or whatsoever from it)? in all files there is a (c) 2021 Matías Godoy.
If i need to add or remove anything from my files, please let me know!! (https://github.com/pcace/open-rally-computer/tree/dev)
the changes i made to the code are:
- use different display and library
-use sd card for memory (i know fram is much more reliable, but i just had non laying around...)
- use sd card for recording track
- add webserver wich provides recorded tracks
- add 2d Compass in the heading menu
- read voltage from voltage devider and add to status bar
- add "save-POI" function when in "track" page

and thanks again for this awesome project!!

mattogodoy, 2024-08-06:
Hi there!
First of all, I wanted to thank you for asking. Not many people think of these things, and they are important in the open-source world :)

A brief summary of [the license I've set for this project](https://github.com/mattogodoy/open-rally-computer?tab=GPL-3.0-1-ov-file#readme) is that you can do whatever you want with it, even make money! The only condition is that you have to keep your variant of the project along with all of your changes open-source and available to anyone who wants to see or use it for themselves. You cannot make a close-sourced variant of this project.

As far as I can see, you are already complying as your repo is public and I can see all your changes, which by the way are really good additions to the project!

If you have pictures of your changes (how the device looks, how the tracks look, etc) and can add them here, it would make me really happy to see them. It brings me a lot of joy knowing that the project is being useful to someone else.

Best of luck, and I hope you enjoy your Open Rally Computer 🚀

pcace, 2024-08-06:
Hi, thanks for your warm reply! i will definitely update the readme.md in the next days reflecting the changes i have made to the code, and try to make some ok pictures of the cable-mess i have created here ;) Like i said - it is more a playground for me then the goal to have a bullet prove rally computer ( although it already did around 2000km on my WR450 with my codebase and worked pretty good ;) )

pcace, 2024-08-06:
updated the manual and readme
https://github.com/pcace/open-rally-computer/commit/42198d1d75e1d2708391b3459bd140808c60dbc8

when i find some more time, i will go through it more in depth!

Closed 2024-08-06.

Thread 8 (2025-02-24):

odometer precision?

pcace, 2025-02-24:
Hi there,

what is your experience with the precision of the odometer functionality?
i have tried different GPS (Ublox Neo 6m als well as LC86G) usually with pretty good hdop using the open-rally-computer. but i have an almost 15% lower distance reading compared to the reality (measured from gpx track).

is there anything i could check or improve in the code?

Any idea would be great!

thanks a lot

mattogodoy, 2025-03-01:
Hi there! Sorry for the late reply.
The UBlox Neo 6M is a fairly old GPS module by now, that (if I remember correclty) only supports US GPS satellites and has a slow update rate.
For the latest modules I used the [Beitian BE-220 GPS Module](https://www.aliexpress.com/item/1005007535403581.html), which is newer and receives information from the BeiDou (chinese), Galileo (european) and GLONASS (russian) constellations. This greatly improves GPS lock times and precision. As a plus, it also has a faster refresh rate.
I'd recommend you to try that module and hopefully it will improve things by a lot.

Another thing that you must have in mind is that the track you are following has been recorded with another GPS device, with its own set of errors, so it will never match 100%, even if you use the same GPS device that was used to create the track. This said, 15% is quite high and should be a smaller difference.

Let me know if you find this useful, and good luck!

pcace, 2025-03-03:
No worries, i will try out the Module you recommended. The one i am currently using (LC86G) is also quite capable and usually way better in every sense then the old Neo 6M, and also has 10Hz refresh rate.
i will see if it gets better :)
Thanks for your reply!

mattogodoy, 2025-03-03:
No worries!
For the Neo 6M the cold start was horrible. It took ages.
With the Beitian it's a mixed bag. It's usually quite fast (30 seconds to 1 minute), but sometimes it can take ~2-4 minutes if it's been off for a long time, or if you turn it on in a location far away from the one you turned it off before.

pcace, 2025-03-04:
> This sounds like a small amount of time, but when you are at a rally, you are usually in a hurry and these times are non-trivial.

exactly. i am currently using a separate battery to jeep the module running for some minutes, even if the bike is turned off. so that it does not loose the sat connection on small stops.

cheers

Closed 2025-03-04.

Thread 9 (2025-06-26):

Easy-to-Build Fork with Adafruit Feather and FeatherWing Hardware

adamshatzkamer, 2025-06-26:
Hi everyone,

First, thank you for creating and maintaining this amazing project! It's a fantastic resource for the community, and we truly appreciate all the hard work that has gone into it.

We wanted to share that we've created a fork of this project that focuses on making it easier to assemble using Adafruit Feather boards and FeatherWing accessories. This version is designed to simplify hardware selection and wiring, making it more accessible for beginners and hobbyists.

Key Features of the Fork:
Adafruit Feather HUZZAH32: A compact and powerful ESP32-based board.
Adafruit TFT FeatherWing - 3.5" 480x320 Touchscreen: A plug-and-play display with touchscreen functionality.
Adafruit Ultimate GPS FeatherWing: For GPS functionality, with a recommendation to use an external GPS antenna for better reception.
Simplified Wiring: All components are designed to stack directly, minimizing the need for manual wiring.
Updated Documentation: Includes detailed instructions for hardware assembly, wiring, and setup.
You can find the fork here: [https://github.com/adamshatzkamer/open-rally-computer]

We hope it's okay that we created this fork to make the project more accessible for users with Adafruit Feather hardware. We hope this fork can help others get started more easily with this fantastic project. Feedback and suggestions are always welcome!

Thank you again for all your hard work and for sharing this project with the community.

Best regards,
Adam Shatzkamer

adamshatzkamer, 2025-06-26:
I think I got the hyperlink wrong, trying again!

[https://github.com/adamshatzkamer/open-rally-computer](https://github.com/adamshatzkamer/open-rally-computer)

mattogodoy, 2025-07-18:
Hi there!
I'm very sorry for the amount of time it took me to reply. Life is hectic right now 😆

Of course it's ok. It's more than ok, it's encouraged!
I'm very glad people is finding my project useful and keeping it alive. Adding modifications is part of the game.

I'll add the link to the README file so others can find it easily 🙂

Thank you for sharing it with us!

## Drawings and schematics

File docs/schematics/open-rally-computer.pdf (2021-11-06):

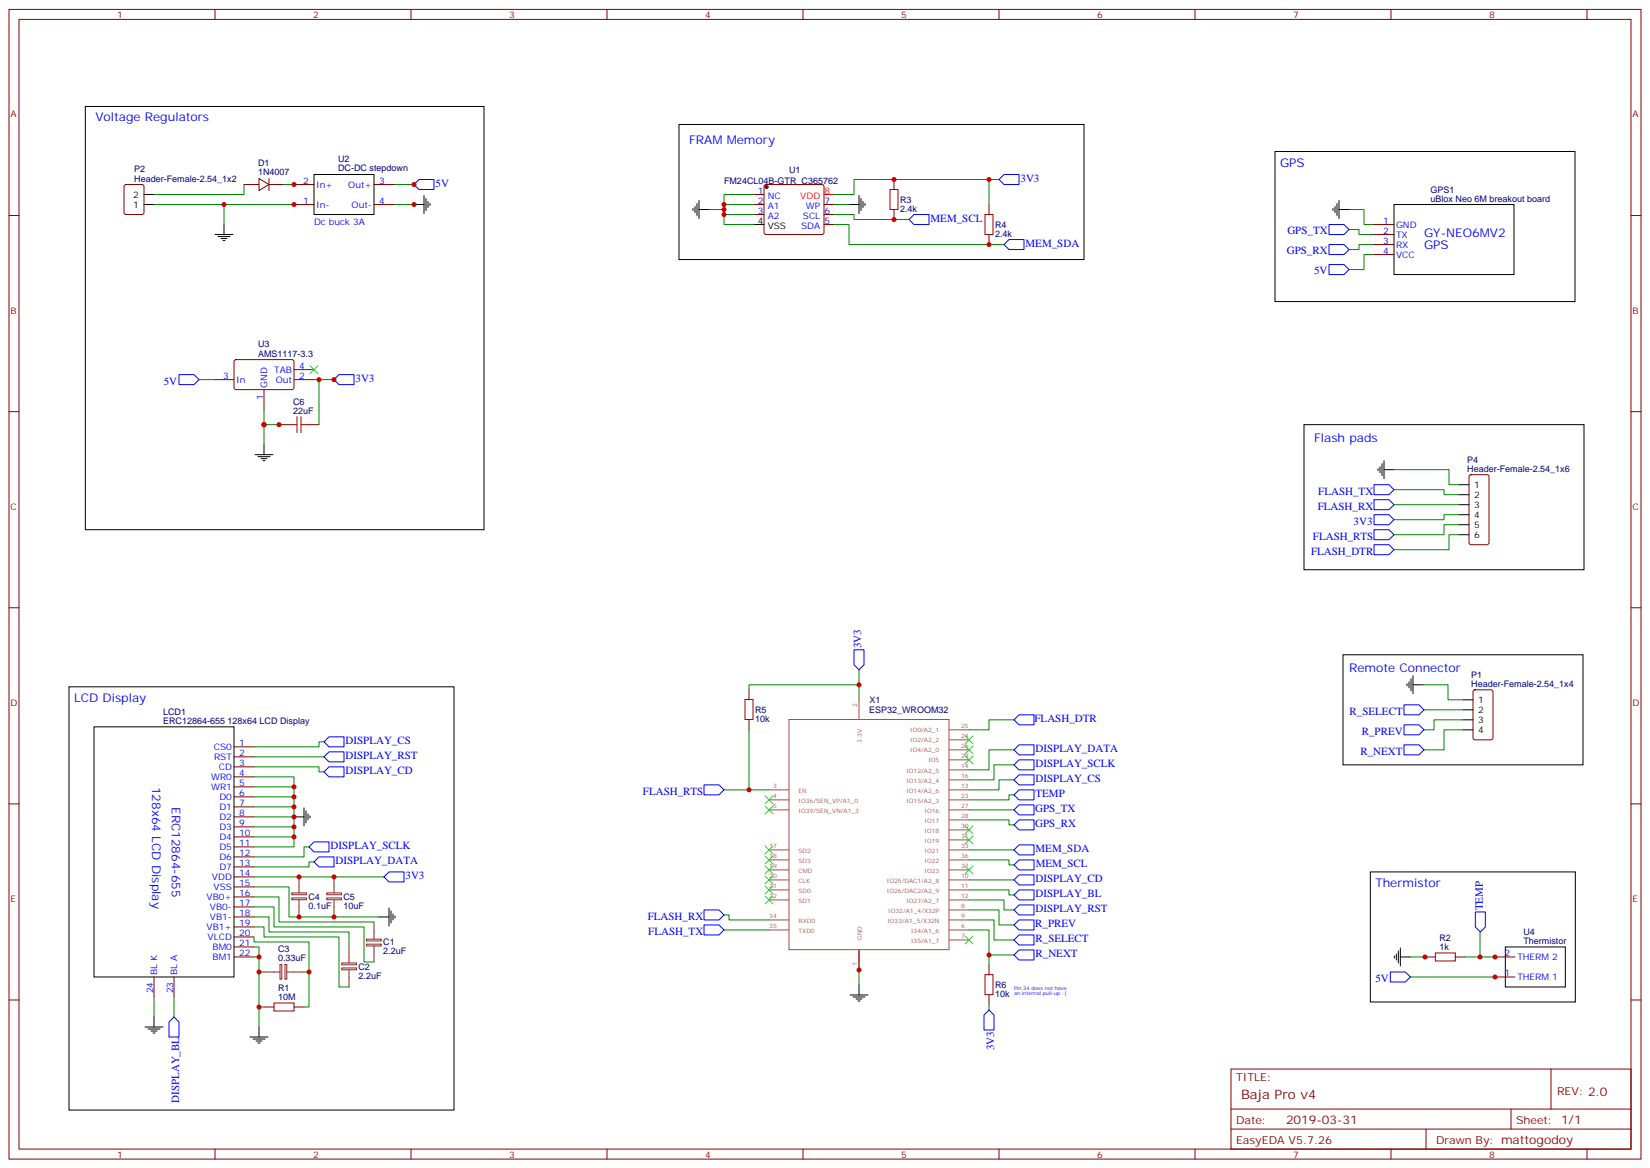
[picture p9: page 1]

GPS1
uBlox Neo 6M breakout board

R6 Pin 34 does not have

an internal pull-up :(

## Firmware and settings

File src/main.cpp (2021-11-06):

// Open Rally Computer
// Copyright (C) 2021  Matías Godoy

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

#include <Arduino.h>
#include <pins.h>
#include <display.h>
#include <gps.h>
#include <buttons.h>
#include <thermistor.h>
#include <memory.h>

unsigned long previousMillis = 0;
unsigned long currentMillis = 0;

void setup(void) {
  // Serial port for debugging
  Serial.begin(115200);

  // Initialize GPS module
  initializeGps();

  // Try to load config
  loadConfig(); // Config is loaded before drawing the splash screen to check if flipped 180º

  // Initialize graphic library
  initializeDisplay();

  // Draw splash screen
  drawSplashScreen();

  initButtons();

  delay(2000);
  state.currentScreen = SCREEN_ODOMETER;
}

void loop(void) {
  u8g2->clearBuffer();
  drawScreen(state.currentScreen);
  u8g2->sendBuffer();

  checkButtons();
  pollGpsModule();

  // Tasks that occur every 1 second
  currentMillis = millis();
  if (currentMillis - previousMillis > 1000) {
    previousMillis = currentMillis;
    updateGpsValues();
    // updateTemperature();
    saveConfig(); // Save all to FRAM
  }
}

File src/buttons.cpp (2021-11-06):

// Open Rally Computer
// Copyright (C) 2021  Matías Godoy

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

#include <buttons.h>
#include <screens/input.h>
#include <ButtonEventCallback.h>
#include <PushButton.h>
#include <Bounce2.h>
#include <U8g2lib.h>
#include <pins.h>
#include <memory.h>
#include <screens.h>
#include <ota.h>
#include <menu.h>
#include <display.h>

PushButton button_select = PushButton(PIN_BUTTON_SELECT, ENABLE_INTERNAL_PULLUP);
PushButton button_next = PushButton(PIN_BUTTON_NEXT, ENABLE_INTERNAL_PULLUP);
PushButton button_prev = PushButton(PIN_BUTTON_PREV, ENABLE_INTERNAL_PULLUP);
int holdMultiplier = 1;

// This replaces the UI buttons functionality on u8g2 with mine
// Otherwise, I can't read button inputs while on the settings screen
uint8_t u8x8_GetMenuEvent(u8x8_t* u8x8) {
  checkButtons();

  int cmd = state.menuLastCommand;
  state.menuLastCommand = 0;

  return cmd;
}

void onButtonSelectRelease(Button& btn, uint16_t duration) {
  state.selectButtonPressedSince = 0;

  // This avoids calling this callback when releasing
  // the center button after a Hold event
  if (duration >= BTN_HOLD_SKIP_DELAY)
    return void();

  switch (state.currentScreen) {
    case SCREEN_ODOMETER:
      state.currentScreen = SCREEN_SPEED;
      break;
    case SCREEN_SPEED:
      state.currentScreen = SCREEN_TIME;
      break;
    case SCREEN_TIME:
      state.currentScreen = SCREEN_HEADING;
      break;
    case SCREEN_HEADING:
      state.currentScreen = SCREEN_ODOMETER;
      break;
    case SCREEN_MENU:
      state.menuLastCommand = U8X8_MSG_GPIO_MENU_SELECT;
      break;
    case SCREEN_INPUT:
      saveInputValue();
      break;
    case SCREEN_LANGUAGE:
      state.menuLastCommand = U8X8_MSG_GPIO_MENU_SELECT;
      break;
    case SCREEN_UPDATE:
      if (state.updatingFirmware == 1)
        return void();

      switch (state.currentUpdateStep) {
        case UPDATE_START:
          checkLatestVersion();
          break;
        case UPDATE_CONN_ERROR:
        case UPDATE_UPGR_ERROR:
        case UPDATE_FINISHED:
          state.currentUpdateStep = UPDATE_START;

          // Go back to menu
          state.currentScreen = SCREEN_MENU;
          break;

        default:
          checkLatestVersion();
          break;
      }
      break;
    case SCREEN_SPLASH:
      // Go back to menu
      state.currentScreen = SCREEN_MENU;
      break;
  }
}

void onButtonSelectPress(Button& btn) {
  switch (state.currentScreen) {
    case SCREEN_ODOMETER:
    case SCREEN_SPEED:
    case SCREEN_TIME:
    case SCREEN_HEADING:
      state.selectButtonPressedSince = millis();
      break;
  }
}


void onButtonSelectHold(Button& btn, uint16_t duration) {
  switch (state.currentScreen) {
    case SCREEN_ODOMETER:
      memory.config.tripPartial = 0;
      state.alreadySaved = false; // Indicate that changes has been made
      break;
    case SCREEN_SPEED:
      state.currentScreen = SCREEN_MENU;
      break;
    case SCREEN_TIME:
      state.currentScreen = SCREEN_MENU;
      break;
    case SCREEN_HEADING:
      state.currentScreen = SCREEN_MENU;
      break;
    case SCREEN_MENU:
      state.currentScreen = SCREEN_ODOMETER;
      state.menuLastCommand = U8X8_MSG_GPIO_MENU_HOME;
      break;
    case SCREEN_INPUT:
      state.currentScreen = SCREEN_MENU;
      state.inputValue = 0;
      break;
    case SCREEN_LANGUAGE:
      state.menuLastCommand = U8X8_MSG_GPIO_MENU_HOME;
      state.currentScreen = SCREEN_MENU;
      break;
    case SCREEN_GPS:
      state.currentScreen = SCREEN_ODOMETER;
      state.menuLastCommand = U8X8_MSG_GPIO_MENU_HOME;
      break;
    case SCREEN_UPDATE:
      if (state.updatingFirmware == 1)
        return;

      state.menuLastCommand = U8X8_MSG_GPIO_MENU_HOME;
      state.currentScreen = SCREEN_MENU;
      break;
  }
}


void onButtonNextPress(Button& btn) {
  switch (state.currentScreen) {
    case SCREEN_ODOMETER:
      // Only change the distance if we are not in QuickView
      if (state.quickViewScreen == 0 && millis() > 3000) { // The second condition prevents a glitch on boot
        if (memory.config.precision == 1) {
          memory.config.tripPartial += 0.1 * holdMultiplier;
        } else {
          memory.config.tripPartial += 0.01 * holdMultiplier;
        }
      }
      break;
    case SCREEN_SPEED:
    case SCREEN_TIME:
    case SCREEN_HEADING:
      // QuickView function for these screens
      if (memory.config.quickViewEnabled) {
        state.quickViewScreen = state.currentScreen;
        state.currentScreen = SCREEN_ODOMETER;
      }
      break;
    case SCREEN_MENU:
      state.menuLastCommand = U8X8_MSG_GPIO_MENU_PREV; // Weird error switches Next with Prev
      break;
    case SCREEN_INPUT:
      state.inputValue++;
      if (state.menuCurrentSelection == MENU_BACKLIGHT)
        setBacklight(state.inputValue);
      break;
    case SCREEN_LANGUAGE:
      state.menuLastCommand = U8X8_MSG_GPIO_MENU_PREV; // Weird error switches Next with Prev
      break;
  }
}


void onButtonNextHold(Button& btn, uint16_t duration, uint16_t repeatCount) {
  if (duration > 5000) holdMultiplier = 5;
  if (duration > 10000) holdMultiplier = 10;

  onButtonNextPress(btn);
}


void onButtonNextRelease(Button& btn, uint16_t duration) {
  holdMultiplier = 1; // Restore multiplier to 1
  state.alreadySaved = false; // Indicate that changes has been made

  // QuickView function
  if (state.quickViewScreen != 0 && state.currentScreen == SCREEN_ODOMETER) {
    state.currentScreen = state.quickViewScreen;
    state.quickViewScreen = 0; // Reset the quickView so it does not work when you are in the Odometer screen
  }
}


void onButtonPrevPress(Button& btn) {
  switch (state.currentScreen) {
    case SCREEN_ODOMETER:
      // Only change the distance if we are not in QuickView
      if (state.quickViewScreen == 0 && millis() > 3000) { // The second condition prevents a glitch on boot
        if (memory.config.precision == 1) {
          memory.config.tripPartial -= 0.1 * holdMultiplier;
        } else {
          memory.config.tripPartial -= 0.01 * holdMultiplier;
        }
        if (memory.config.tripPartial < 0) memory.config.tripPartial = 0;
      }
      break;
    case SCREEN_SPEED:
    case SCREEN_TIME:
    case SCREEN_HEADING:
      // QuickView function for these screens
      if (memory.config.quickViewEnabled) {
        state.quickViewScreen = state.currentScreen;
        state.currentScreen = SCREEN_ODOMETER;
      }
      break;
    case SCREEN_MENU:
      state.menuLastCommand = U8X8_MSG_GPIO_MENU_NEXT;
      break;
    case SCREEN_INPUT:
      state.inputValue--;
      if (state.menuCurrentSelection == MENU_BACKLIGHT) {
        if (state.inputValue < 0) state.inputValue = 0;
        setBacklight(state.inputValue);
      }
      break;
    case SCREEN_LANGUAGE:
      state.menuLastCommand = U8X8_MSG_GPIO_MENU_NEXT;
      break;
  }
}
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

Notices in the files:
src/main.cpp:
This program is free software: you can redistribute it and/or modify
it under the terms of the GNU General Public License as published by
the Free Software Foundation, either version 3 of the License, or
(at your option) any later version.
